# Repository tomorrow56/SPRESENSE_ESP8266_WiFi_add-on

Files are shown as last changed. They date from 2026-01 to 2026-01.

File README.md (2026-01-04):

# SPRESENSE Wi-Fi Add-on

 [English](README_EN.md)

## 概要
Sonyの省電力で高性能なIoT開発ボードSPRESENSEにWi-FI機能を追加するためのアドオンボードです。
ESP8266(ESP-WROOM-02, 技適取得済)を搭載、SPRESENSEとEP8266の間の通信は [Espressif標準のATコマンド](ESP8266_AT_command/) を使用します。

## 主な仕様
- ESP8266(ESP-WROOM-02)を搭載
- SPRESENSEメインボード上面の拡張コネクタに直接装着可能（レベルシフタ搭載）
- ハーフサイズ設計で他のハーフサイズモジュールと同時に使用可能
- I2C・SPI接続のモジュールとの同時使用が可能（一部制限あり）
- 技適取得済み

### v2.2について(2026年1月リリース)
従来のバージョン(v1.1)と比較して、以下の変更があります：
- ESP8266 Deep sleep機能への対応

この対応のため、リセット回路の設計を変更しました。そのため、従来のv1.1のソフトウエアを使用する場合は、以下のリセットピン(D21)の制御の追加が必要となります。

```cpp
#define rst_pin PIN_D21   // ESP8266のリセットピン, Hでリセット

void setup() {
  // ESP8266のリセットピンの設定
  pinMode(rst_pin, OUTPUT);
  // ESP8266のリセットを解除する(リセットピンをLにする)
  digitalWrite(rst_pin, LOW);

```

## 製品画像 (基板の色は予告なく変更になる場合があります)

### v1.1

#### 基板表面

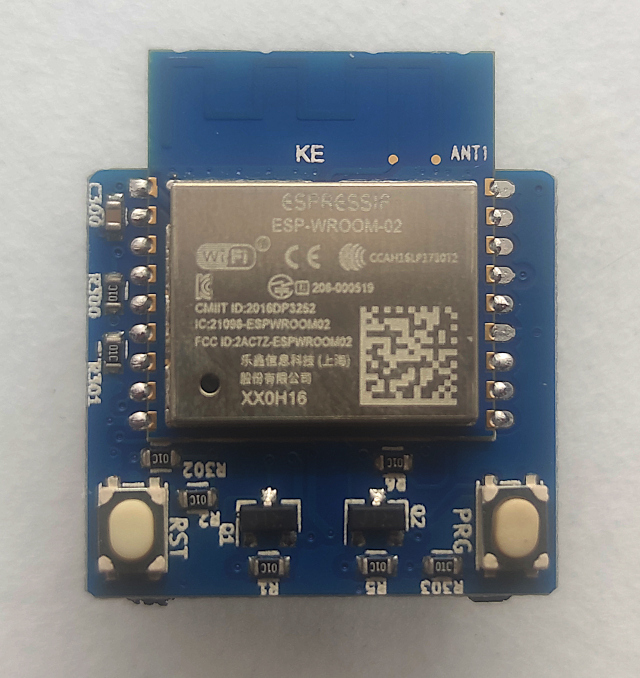
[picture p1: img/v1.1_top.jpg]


#### 基板裏面

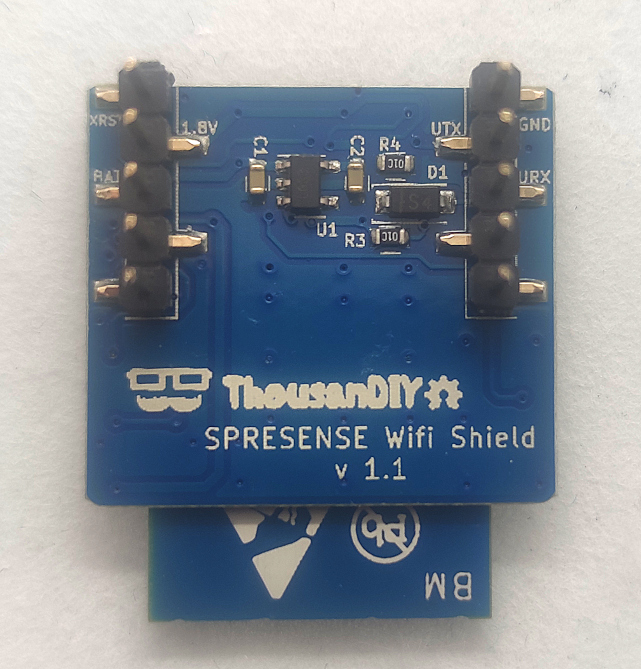
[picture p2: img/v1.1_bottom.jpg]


#### SPRESENSEへ取り付けた状態 (SPRESENSEは付属しません)

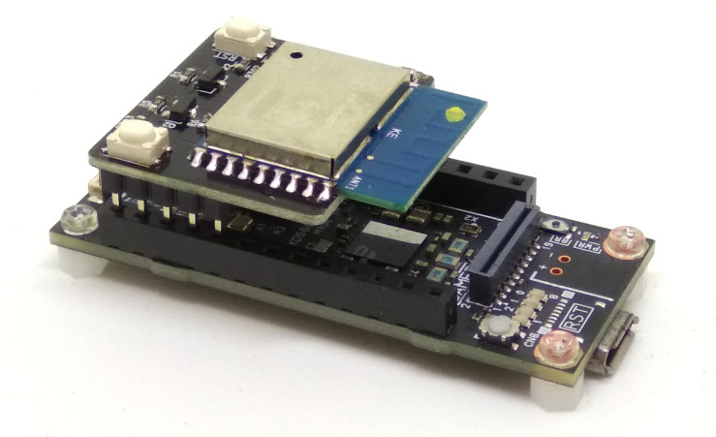
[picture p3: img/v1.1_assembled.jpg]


### v2.2

#### 基板表面

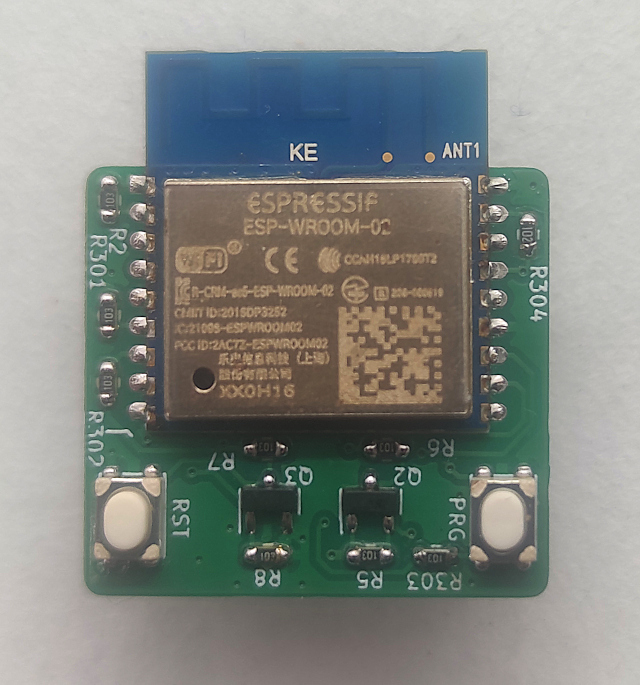
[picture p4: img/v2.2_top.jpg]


#### 基板裏面

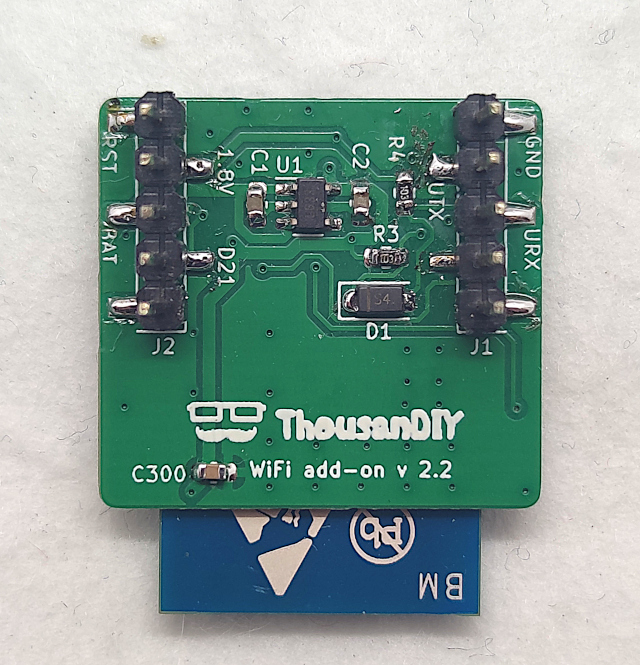
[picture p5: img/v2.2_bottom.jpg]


#### SPRESENSEへ取り付けた状態 (SPRESENSEは付属しません)

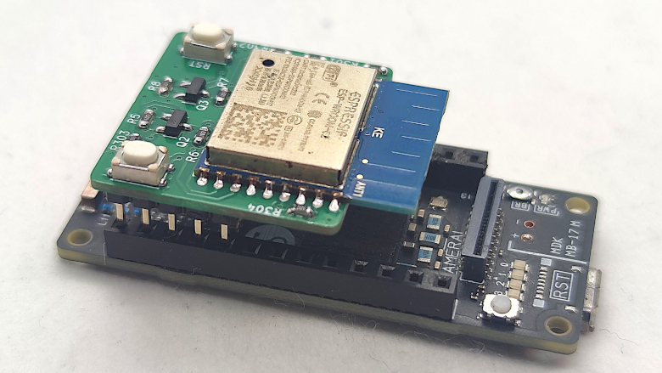
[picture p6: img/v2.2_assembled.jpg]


## 回路図

### v1.1回路図

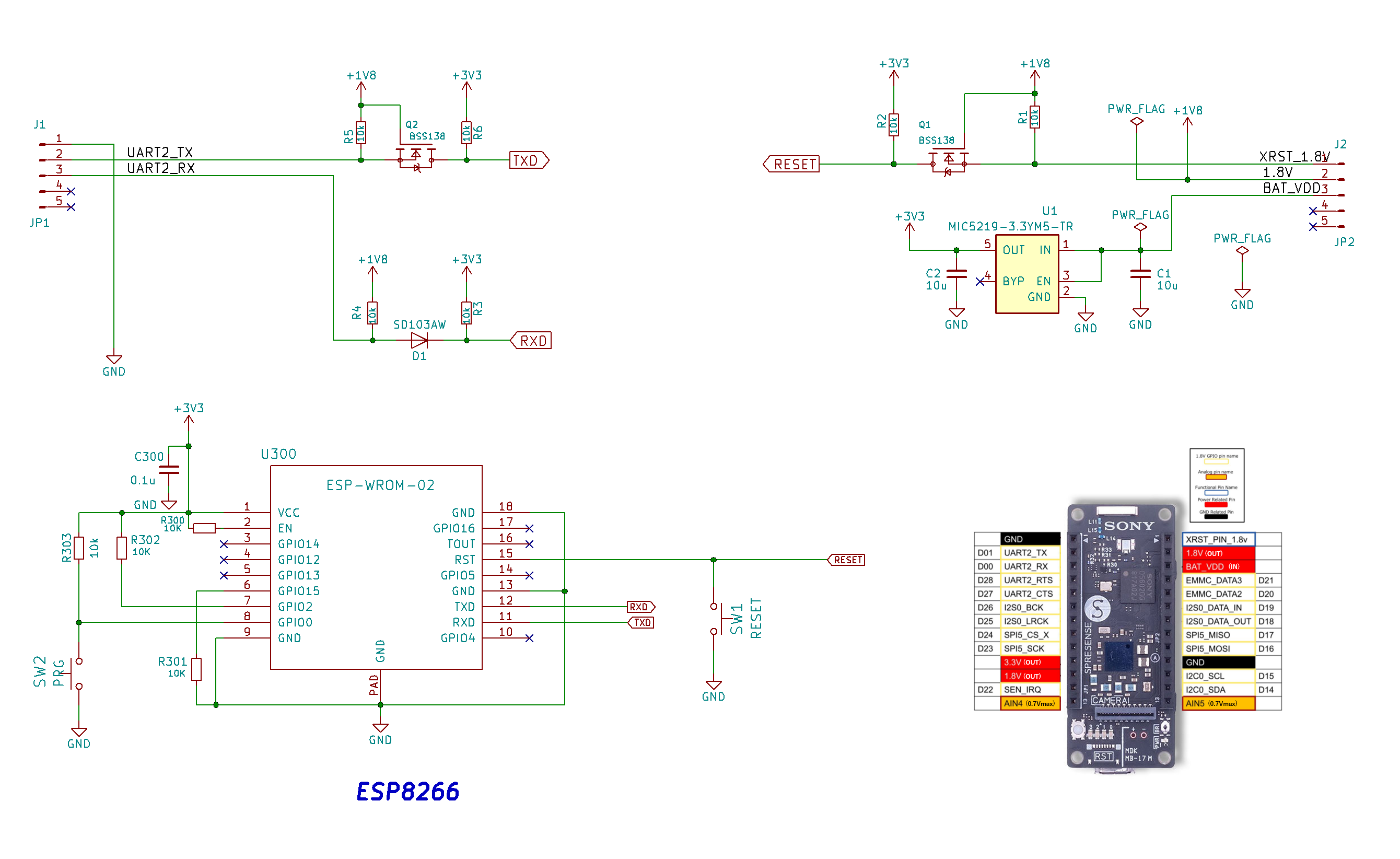
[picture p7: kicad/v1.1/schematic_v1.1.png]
v1.1回路図


### v2.2回路図

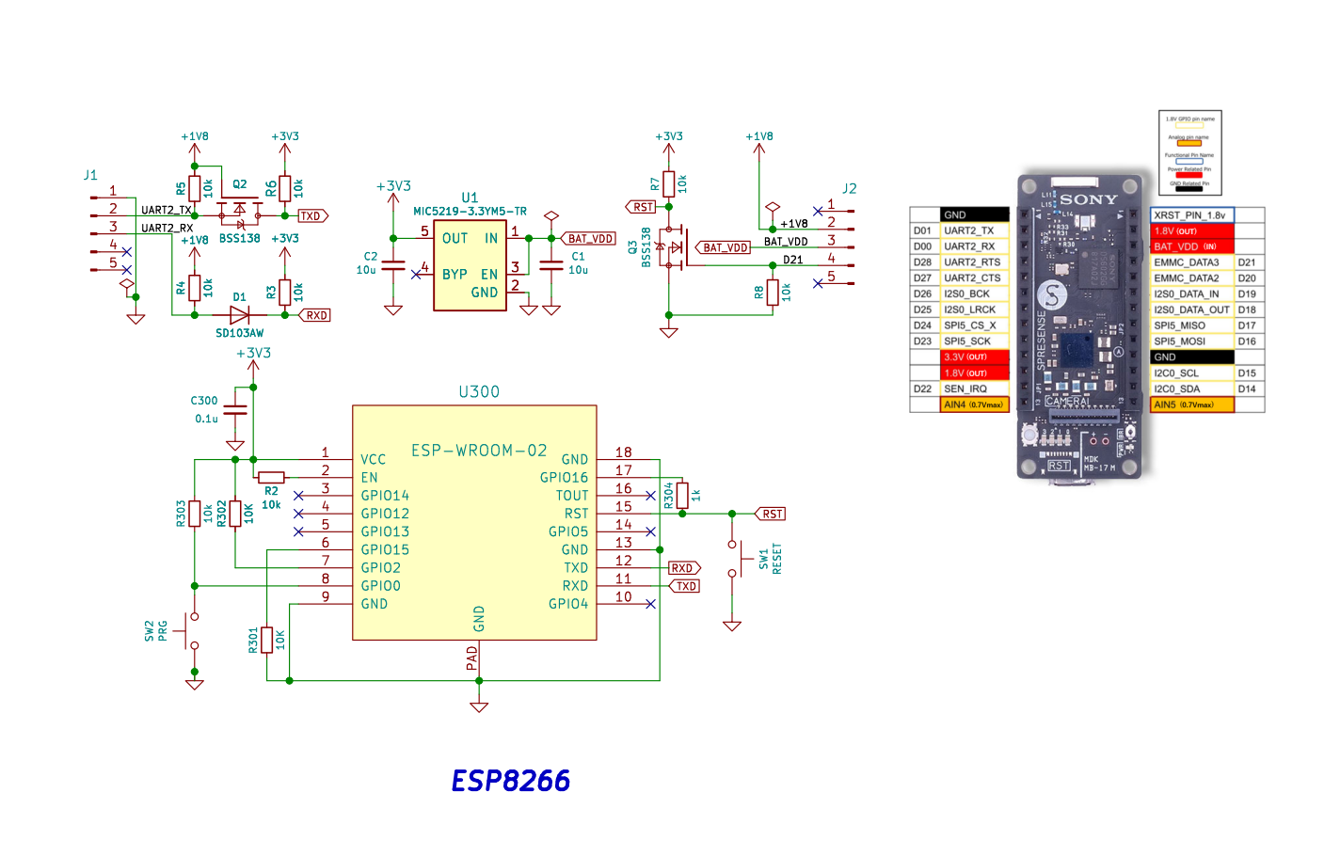
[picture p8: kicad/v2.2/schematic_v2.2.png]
v2.2回路図


## 基板設計データ

基板設計データはKiCadプロジェクト形式で提供されています。
- v1.1: `kicad/v1.1/`
- v2.2: `kicad/v2.2/`

各バージョンの基板設計データには、回路図、PCBレイアウト、部品リストなどが含まれています。

## サンプルコード

各バージョンのサンプルコードは、`example/`ディレクトリ以下に格納されています。
- v1.1: `example/v1.1/`
- v2.2: `example/v2.2/`

各サンプルコードは、SPRESENSEのArduino IDE環境で動作するように設計されています。
詳細な使用方法は各サンプルコードのコメントを参照してください。

## ライセンス

このプロジェクトはGNU General Public License v3.0ライセンスの下で提供されます。詳細は[LICENSE](LICENSE)ファイルを参照してください。

## 作者

- [tomorrow56](https://github.com/tomorrow56)

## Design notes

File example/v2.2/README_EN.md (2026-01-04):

# SPRESENSE v2.2 Examples

[日本語](README.md)

## Overview

This directory contains sample programs for the SPRESENSE Wi-Fi add-on v2.2. Version 2.2 supports ESP8266 Deep Sleep functionality, and when combined with SPRESENSE's Cold Sleep feature, it can significantly reduce power consumption during battery operation.

## Sample List

### 1. SPRESENSE_PIR_to_LINE

This is a low-power IoT application that sends messages to the LINE Messaging API via SPRESENSE and ESP8266, triggered by PIR (motion) sensor interrupt detection.

#### Features

- **Ultra-low power design**: Reduces power consumption to several μA by putting ESP8266 in Deep Sleep and SPRESENSE in Cold Sleep during standby
- **Event-driven**: Automatically wakes up when the PIR sensor detects human presence, sends messages, and returns to sleep mode
- **Real-time notifications**: Can send instant notifications to the LINE app

#### Operation Overview

1. **Initialization**: Initialize SPRESENSE and ESP8266, establish Wi-Fi connection
2. **Sleep transition**: Put ESP8266 in Deep Sleep and SPRESENSE in Cold Sleep
3. **Event detection**: PIR sensor detects human presence and wakes up SPRESENSE
4. **Processing**: Wake up ESP8266 and send messages via LINE Messaging API
5. **Return to sleep**: Return both chips to sleep mode after processing completion

#### Required Hardware

- SPRESENSE main board
- SPRESENSE Wi-Fi add-on v2.2
- PIR sensor module (output: HIGH/LOW digital signal)
- Power supply (battery or USB power)

#### Configuration

The following settings are required before use:

- Wi-Fi access point information (SSID, password)
- LINE Messaging API channel access token
- Destination LINE group or user ID

For detailed configuration methods, please refer to the comments in each sketch.

### 2. Library/ESP8266_LINE_Messaging_API

An Arduino library for easily using the LINE Messaging API with SPRESENSE + ESP8266.

#### Features

- LINE Messaging API v3.0 compatible
- Text message sending functionality
- Simple initialization and authentication process
- Error handling functionality

#### Usage

After installing the library in Arduino IDE, follow these steps with reference to the sample sketch:

1. Include the library
2. Set the access token
3. Establish Wi-Fi connection
4. Call the message sending function

For detailed API reference, please refer to the comments in the library.

## Power Saving Features

### Deep Sleep (ESP8266)

- Power consumption: Approx. 10μA
- Wake-up time: Approx. 200ms
- Wakes up via reset pin (D21) control

### Cold Sleep (SPRESENSE)

- Power consumption: Approx. 1μA (excluding RTC)
- Wake-up time: Approx. 1ms
- Wakes up via GPIO interrupt

### Combined Effect

By combining both sleep functions, the operating life during battery operation can be significantly extended. For example, for applications that detect events several times per day, operation for several months to years with coin batteries is possible.

## Important Notes

- This sample is exclusive to SPRESENSE Wi-Fi add-on v2.2. It does not work with v1.1.
- Deep Sleep functionality requires connection of the reset pin (D21).
- Sleep power consumption varies depending on supply voltage and ambient temperature.
- Internet connection is required for using LINE Messaging API.

## License

Each sample code and library is provided under the GNU General Public License v3.0, same as the entire project.

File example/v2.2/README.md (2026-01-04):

# SPRESENSE v2.2 Examples

[English](README_EN.md)

## 概要

このディレクトリには、SPRESENSE Wi-Fi add-on v2.2 を使用したサンプルプログラムが含まれています。v2.2 では ESP8266 の Deep Sleep 機能に対応し、SPRESENSE の Cold Sleep 機能と組み合わせることで、バッテリー駆動時の消費電力を大幅に削減できます。

## サンプル一覧

### 1. SPRESENSE_PIR_to_LINE

PIR（人感）センサーの割込み検出をトリガーとして、SPRESENSEとESP8266経由でLINE Messaging APIにメッセージを送信する省電力IoTアプリケーションです。

#### 特徴

- **超低消費電力設計**: 待機時は ESP8266 を Deep Sleep、SPRESENSE を Cold Sleep にすることで、消費電力を数μAレベルに抑制
- **イベント駆動**: PIRセンサーによる人体検出で自動的に起動し、メッセージ送信後に再びスリープ状態へ移行
- **リアルタイム通知**: LINEアプリに即時通知を送信可能

#### 動作概要

1. **初期化**: SPRESENSEとESP8266を初期化し、Wi-Fi接続を確立
2. **スリープ移行**: ESP8266をDeep Sleep、SPRESENSEをCold Sleepに移行
3. **イベント検出**: PIRセンサーが人体を検出し、SPRESENSEを起動
4. **処理実行**: ESP8266を起動し、LINE Messaging API経由でメッセージを送信
5. **再スリープ**: 処理完了後、再び両チップをスリープ状態へ

#### 必要なハードウェア

- SPRESENSEメインボード
- SPRESENSE Wi-Fi add-on v2.2
- PIRセンサーモジュール（出力：HIGH/LOWデジタル信号）
- 電源（バッテリーまたはUSB電源）

#### 設定

使用前に以下の設定が必要です：

- Wi-Fiアクセスポイント情報（SSID、パスワード）
- LINE Messaging APIのチャネルアクセストークン
- 通知先のLINEグループまたはユーザーID

詳しい設定方法は、各スケッチのコメントを参照してください。

### 2. Library/ESP8266_LINE_Messaging_API

LINE Messaging APIをSPRESENSE + ESP8266で簡単に利用するためのArduinoライブラリです。

#### 機能

- LINE Messaging API v3.0対応
- テキストメッセージ送信機能
- 簡単な初期化と認証処理
- エラーハンドリング機能

#### 使用方法

ライブラリをArduino IDEにインストール後、サンプルスケッチを参考に以下の手順で使用します：

1. ライブラリをインクルード
2. アクセストークンを設定
3. Wi-Fi接続を確立
4. メッセージ送信関数を呼び出し

詳細なAPIリファレンスはライブラリ内のコメントを参照してください。

## 省電力機能について

### Deep Sleep (ESP8266)

- 消費電力: 約10μA
- 起動時間: 約200ms
- リセットピン（D21）制御で起動

### Cold Sleep (SPRENSE)

- 消費電力: 約1μA（RTC除く）
- 起動時間: 約1ms
- GPIO割込みで起動

### 組合せ効果

両スリープ機能を組み合わせることで、バッテリー駆動時の動作寿命を大幅に延長できます。例えば、1日数回のイベント検知用途であれば、コイン電池での数ヶ月〜数年の駆動も可能です。

## 注意事項

- 本サンプルはSPRESENSE Wi-Fi add-on v2.2専用です。v1.1では動作しません。
- Deep Sleep機能を使用するため、リセットピン（D21）の接続が必要です。
- 電源電圧や周囲温度によってスリープ時の消費電力は変動します。
- LINE Messaging APIの利用にはインターネット接続が必要です。

## ライセンス

各サンプルコードおよびライブラリは、プロジェクト全体と同じくGNU General Public License v3.0の下で提供されます。

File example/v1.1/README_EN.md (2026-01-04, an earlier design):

# SPRESENSE v1.1 Examples

[日本語](README.md)

## Overview

This directory contains sample programs for the SPRESENSE Wi-Fi add-on v1.1. Version 1.1 provides basic Wi-Fi communication functionality and can serve as a foundation for various IoT applications.

## Sample List

### 1. SPRESENSE_ESP8266

A simple sample for verifying the basic operation of the Wi-Fi add-on.

#### Features

- Connection to Wi-Fi access points
- HTTP client communication with web servers
- Display of communication status via serial monitor

#### Characteristics

- Basic sample for first-time users of SPRESENSE Wi-Fi add-on
- Learn basic AT command usage
- Ideal for testing ESP8266 communication

### 2. SPRESENSE_ESP8266_ambient

A sample for sending sensor data to Ambient (IoT data visualization service).

#### Features

- Periodic sensor data acquisition
- Data transmission to Ambient server
- Data visualization through graphs

#### Requirements

- Ambient account and channel ID
- Sensors (temperature, humidity, etc.)

### 3. SPRESENSE_SERIAL_TEST

A sample for testing serial communication between SPRESENSE and ESP8266.

#### Features

- Bidirectional serial communication testing
- AT command send/receive verification
- Communication speed and stability verification

### 4. SPRESENSE_Sparkfun_ESP8266_Phant

A sample for sending data to SparkFun Phant service.

#### Features

- Data posting to Phant server
- IoT data logging
- Cloud data store integration

### 5. SPRESENSE_Sparkfun_ESP8266_Ping

A Ping test sample for verifying network connectivity.

#### Features

- Ping transmission to specified hosts
- Network latency measurement
- Connection status monitoring

### 6. SPRESENSE_Sparkfun_ESP8266_Shield_Demo

A demonstration showing basic usage of the SparkFun ESP8266 Shield.

#### Features

- Wi-Fi shield initialization
- Various network service usage examples
- Practical application templates

## Library

### SparkFun ESP8266 AT Arduino Library

Arduino library used in v1.1 samples.

#### Features

- Simple interface for ESP8266 AT commands
- Wi-Fi connection management
- HTTP/TCP/UDP communication
- DNS resolution

#### Usage

1. Install the library in Arduino IDE
2. Open the sample sketch
3. Modify Wi-Fi settings
4. Upload sketch to SPRESENSE

## Hardware Requirements

- SPRESENSE main board
- SPRESENSE Wi-Fi add-on v1.1
- USB cable (for programming)
- Wi-Fi access point

## Configuration

All samples require the following configuration:

```cpp
// Wi-Fi settings
const char* ssid = "your_wifi_ssid";
const char* password = "your_wifi_password";
```

For sample-specific configurations, please refer to the comments in each sketch.

## Important Notes

- This sample is exclusive to SPRESENSE Wi-Fi add-on v1.1
- Does not support v2.2 Deep Sleep functionality
- Requires 2.4GHz band Wi-Fi access points
- Some samples require external service accounts

## License

Each sample code and library is provided under the GNU General Public License v3.0, same as the entire project.

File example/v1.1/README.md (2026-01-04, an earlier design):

# SPRESENSE v1.1 Examples

[English](README_EN.md)

## 概要

このディレクトリには、SPRESENSE Wi-Fi add-on v1.1 を使用したサンプルプログラムが含まれています。v1.1 は基本的なWi-Fi通信機能を提供し、様々なIoTアプリケーションの基礎として利用できます。

## サンプル一覧

### 1. SPRESENSE_ESP8266

Wi-Fi add-onの基本的な動作を確認するためのシンプルなサンプルです。

#### 機能

- Wi-Fiアクセスポイントへの接続
- HTTPクライアントによるWebサーバーとの通信
- シリアルモニターによる通信状態の表示

#### 特徴

- 初めてSPRESENSE Wi-Fi add-onを使用する方向けの基本サンプル
- ATコマンドの基本的な使用方法を学習できます
- ESP8266との通信テストに最適

### 2. SPRESENSE_ESP8266_ambient

Ambient（IoTデータ可視化サービス）にセンサーデータを送信するサンプルです。

#### 機能

- センサーデータの定期的な取得
- Ambientサーバーへのデータ送信
- グラフによるデータ可視化

#### 必要なもの

- AmbientアカウントとチャネルID
- センサー（温度、湿度など）

### 3. SPRESENSE_SERIAL_TEST

SPRESENSEとESP8266間のシリアル通信をテストするサンプルです。

#### 機能

- シリアル通信の双方向テスト
- ATコマンドの送受信確認
- 通信速度と安定性の検証

### 4. SPRESENSE_Sparkfun_ESP8266_Phant

SparkFun Phantサービスにデータを送信するサンプルです。

#### 機能

- Phantサーバーへのデータ投稿
- IoTデータロギング
- クラウドデータストア連携

### 5. SPRESENSE_Sparkfun_ESP8266_Ping

ネットワーク接続を確認するためのPingテストサンプルです。

#### 機能

- 指定ホストへのPing送信
- ネットワーク遅延測定
- 接続状態の監視

### 6. SPRESENSE_Sparkfun_ESP8266_Shield_Demo

SparkFun ESP8266 Shieldの基本的な使用方法を示すデモンストレーションです。

#### 機能

- Wi-Fiシールドの初期化
- 各種ネットワークサービスの利用例
- 実用的なアプリケーションの雛形

## ライブラリ

### SparkFun ESP8266 AT Arduino Library

v1.1サンプルで使用されているArduinoライブラリです。

#### 機能

- ESP8266 ATコマンドの簡単なインターフェース
- Wi-Fi接続管理
- HTTP/TCP/UDP通信
- DNS解決

#### 使用方法

1. Arduino IDEにライブラリをインストール
2. サンプルスケッチを開く
3. Wi-Fi設定を変更
4. スケッチをSPRESENSEに書き込む

## ハードウェア要件

- SPRESENSEメインボード
- SPRESENSE Wi-Fi add-on v1.1
- USBケーブル（プログラミング用）
- Wi-Fiアクセスポイント

## 設定

すべてのサンプルで、以下の設定が必要です：

```cpp
// Wi-Fi設定
const char* ssid = "your_wifi_ssid";
const char* password = "your_wifi_password";
```

各サンプル固有の設定については、スケッチ内のコメントを参照してください。

## 注意事項

- 本サンプルはSPRESENSE Wi-Fi add-on v1.1専用です
- v2.2のDeep Sleep機能には対応していません
- Wi-Fi接続には2.4GHz帯のアクセスポイントが必要です
- 一部のサンプルでは外部サービスのアカウントが必要です

## ライセンス

各サンプルコードおよびライブラリは、プロジェクト全体と同じくGNU General Public License v3.0の下で提供されます。

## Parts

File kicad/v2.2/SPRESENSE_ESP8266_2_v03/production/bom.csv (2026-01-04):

Designator | Footprint | Quantity | Value | LCSC Part #
C1, C2 | 0603 | 2 | 10u
C300 | 0603 | 1 | 0.1u
D1 | D_SOD-123F | 1 | SD103AW
J1 | PinHeader_1x05_P2.54mm_Vertical_SMD_Pin1Right | 1 | JP1
J2 | PinHeader_1x05_P2.54mm_Vertical_SMD_Pin1Left | 1 | JP2
Q2, Q3 | SOT-23 | 2 | BSS138
R2, R3, R301, R302, R303, R4, R5, R6, R7, R8 | 0603 | 10 | 10k
R304 | 0603 | 1 | 1k
SW1 | SW_SPST_PTS810 | 1 | RESET
SW2 | SW_SPST_PTS810 | 1 | PRG
U1 | SOT-23-5 | 1 | MIC5219-3.3YM5-TR
U300 | ESP-13-WROOM-02_2 | 1 | ESP-WROOM-02

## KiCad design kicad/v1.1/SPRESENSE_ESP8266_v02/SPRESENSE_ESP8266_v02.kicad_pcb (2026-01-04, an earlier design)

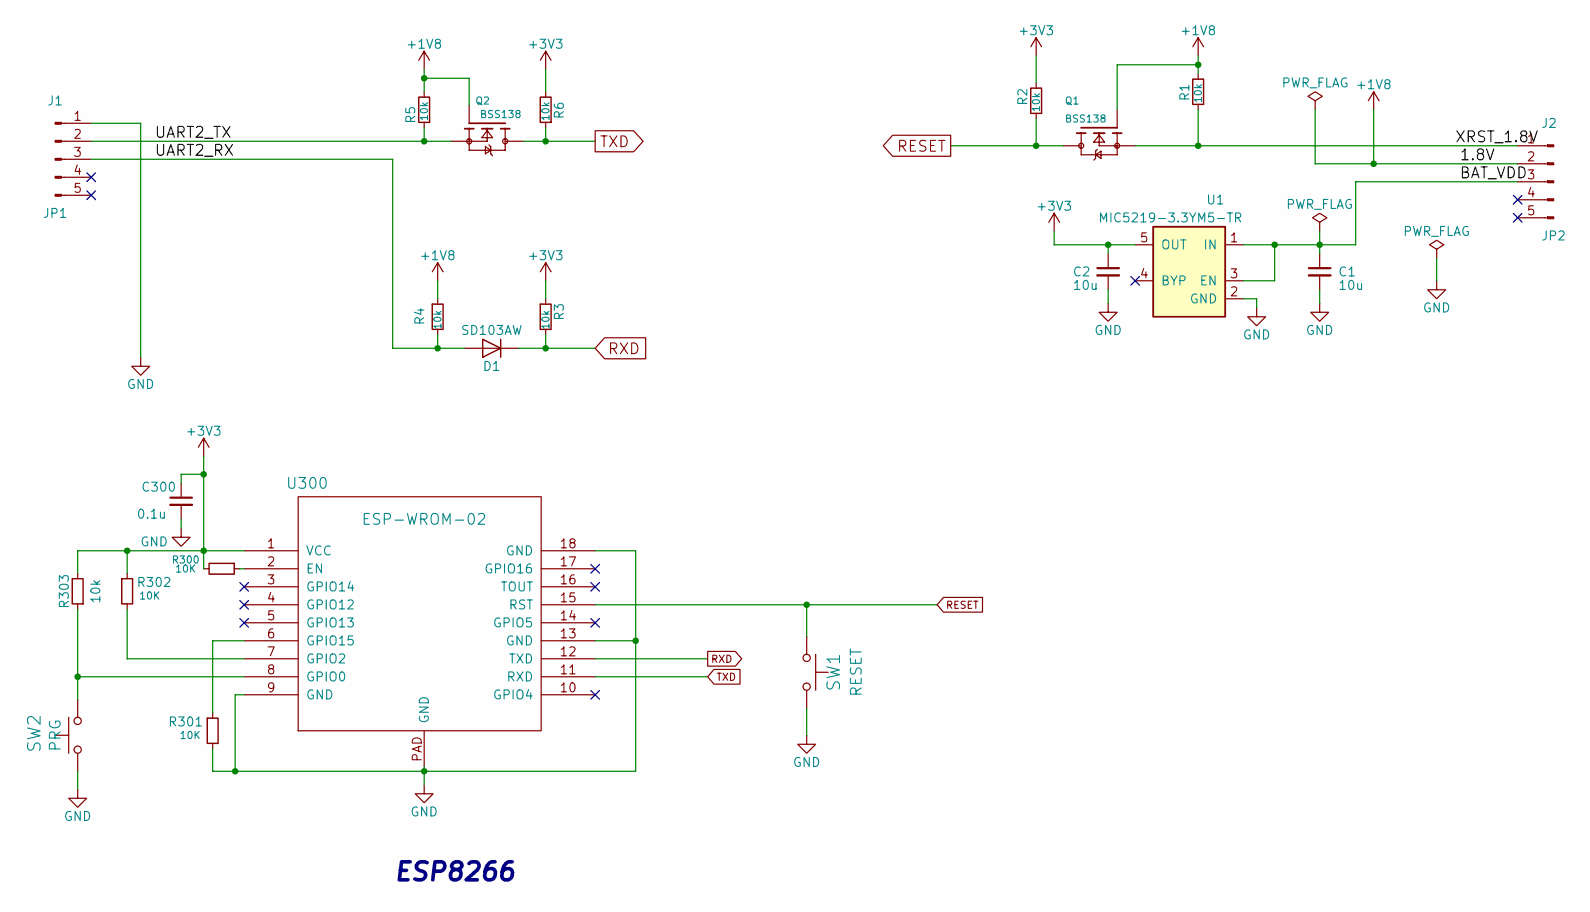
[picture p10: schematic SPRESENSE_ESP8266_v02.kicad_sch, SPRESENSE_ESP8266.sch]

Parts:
C1, C2: 10u; C_0603
C300: 0.1u; C_0603
D1: SD103AW; D_SOD-123F
J1: JP1; Pin_Header_Straight_1x05_Pitch2.54mm_SMD_Pin1Right
J2: JP2; Pin_Header_Straight_1x05_Pitch2.54mm_SMD_Pin1Left
Q1, Q2: BSS138; SOT-23
R1, R2, R3, R4, R5, R6, R303: 10k; R_0603
R300, R301, R302: 10K; R_0603
SW1: RESET; SW_SPST_PTS810
SW2: PRG; SW_SPST_PTS810
U1: MIC5219-3.3YM5-TR; SOT-23-5
U300: ESP-WROM-02; ESP-13-WROOM-02

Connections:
+1V8: J2.2, Q1.1 (G), Q2.1 (G), R1.2, R4.1, R5.2
+3V3: C2.1, C300.1, R2.2, R3.1, R6.2, R300.2, R302.1, R303.2, U1.5 (OUT), U300.1 (VCC)
/BAT_VDD: C1.1, J2.3, U1.1 (IN), U1.3 (EN)
/UART2_RX: D1.2 (A), J1.3, R4.2
/UART2_TX: J1.2, Q2.2 (S), R5.1
/XRST_1.8V: J2.1, Q1.2 (S), R1.1
GND: C1.2, C2.2, C300.2, J1.1, R301.2, SW1.1, SW2.1, U1.2 (GND), U300.9 (GND), U300.13 (GND), U300.18 (GND), U300.PAD (GND)
unnamed: R300.1, U300.2 (EN)
unnamed: R301.1, U300.6 (GPIO15)
unnamed: R302.2, U300.7 (GPIO2)
unnamed: R303.1, SW2.2, U300.8 (GPIO0)
RESET: Q1.3 (D), R2.1, SW1.2, U300.15 (RST)
RXD: D1.1 (K), R3.2, U300.12 (TXD)
TXD: Q2.3 (D), R6.1, U300.11 (RXD)

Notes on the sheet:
ESP8266

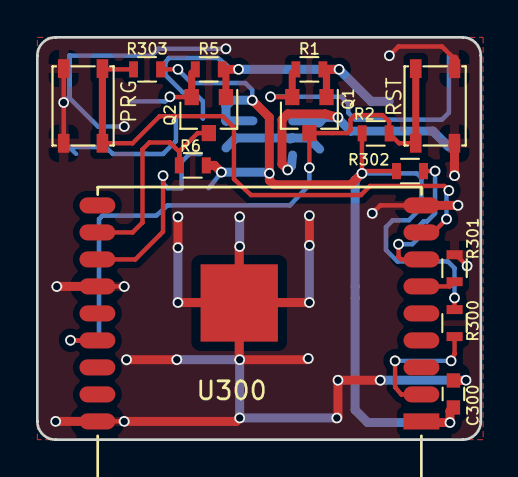
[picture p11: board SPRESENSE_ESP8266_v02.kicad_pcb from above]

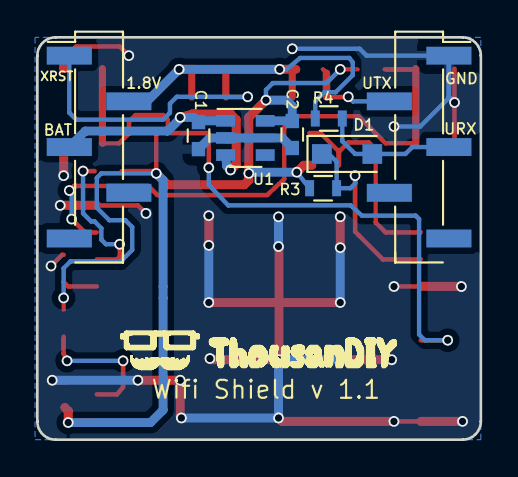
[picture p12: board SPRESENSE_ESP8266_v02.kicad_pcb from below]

Board: 2 copper layers, 24.6 x 22.4 mm, 23 parts (9 on the bottom side), 14 nets.

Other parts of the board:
ref**: val**; TDIY-LOGO-S

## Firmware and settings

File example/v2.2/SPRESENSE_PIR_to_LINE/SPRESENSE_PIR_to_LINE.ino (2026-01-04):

/************************************************************
* ESP8266 WiFi add-on for SPRESENSE
* LINE Messaging API Send Message Library and DeepSleep Example
* Copyright(c) @tomorrow56 All rights reserved.
* ESP8266 baudrate: 115200 baud
************************************************************/

#include "Arduino.h"
#include "LineMessenger.h"
#include <LowPower.h>

#define debug true       // デバッグモード

#define rst_pin PIN_D21   // ESP8266のリセットピン, Hでリセット
#define wake_pin PIN_D14  // SPRESENSEのWakeUpトリガピン, LでWakeUp

// WiFiとLINEの設定
const char* ssid = "<your SSID>";
const char* password = "<your Password>";
// 以下からLINEチャネルアクセストークンを取得する
// https://developers.line.biz/ja/docs/messaging-api/getting-started/
const char* accessToken =  "<your LINE Access Token>";

// Line Messaging API インスタンス作成
LineMessenger line;

bool wakeUpFlag = false;    // WakeUp割り込みフラグ, trueでWakeUp
bool sendCompleteFlag = false;  // LINE Message 送信フラグ, trueで送信完了

bootcause_e bc; // 起動要因を格納する変数

// 起動要因の列挙型
const char* boot_cause_strings[] = {
  "Power On Reset with Power Supplied",
  "System WDT expired or Self Reboot",
  "Chip WDT expired",
  "WKUPL signal detected in deep sleep",
  "WKUPS signal detected in deep sleep",
  "RTC Alarm expired in deep sleep",
  "USB Connected in deep sleep",
  "Others in deep sleep",
  "SCU Interrupt detected in cold sleep",
  "RTC Alarm0 expired in cold sleep",
  "RTC Alarm1 expired in cold sleep",
  "RTC Alarm2 expired in cold sleep",
  "RTC Alarm Error occurred in cold sleep",
  "Unknown(13)",
  "Unknown(14)",
  "Unknown(15)",
  "GPIO detected in cold sleep",
  "GPIO detected in cold sleep",
  "GPIO detected in cold sleep",
  "GPIO detected in cold sleep",
  "GPIO detected in cold sleep",
  "GPIO detected in cold sleep",
  "GPIO detected in cold sleep",
  "GPIO detected in cold sleep",
  "GPIO detected in cold sleep",
  "GPIO detected in cold sleep",
  "GPIO detected in cold sleep",
  "GPIO detected in cold sleep",
  "SEN_INT signal detected in cold sleep",
  "PMIC signal detected in cold sleep",
  "USB Disconnected in cold sleep",
  "USB Connected in cold sleep",
  "Power On Reset",
};

// ESP8266からの受信バッファをクリアする関数
void clearSerial2Buffer() {
  while (Serial2.available() > 0) {
    Serial2.read(); // バッファから1バイトずつ読み出して捨てる
  }
}

// ESP8266をリセットする関数
void resetESP8266() {
  Serial.println("ESP8266 has been reset...");
  digitalWrite(rst_pin, HIGH);  // リセットピンをHにする
  delay(200);
  digitalWrite(rst_pin, LOW);  // リセットピンをLにする

  //ESP8266起動時のゴミデータを捨てる
  delay(250);
  clearSerial2Buffer();

  digitalWrite(LED1, HIGH);  // LED1を点灯
}

// ESP8266をDeep Sleepに移行する関数
void gotoSleepESP8266() {
  // ESP8266をDeep Sleepに移行（最大時間: 約71分、単位はマイクロ秒）
  // AT+GSLP=0は無限スリープ（外部リセットが必要）

  line.sendCommand("AT+GSLP=0", 1000);
  Serial.println("ESP8266 goes to deep sleep mode...");
  
  digitalWrite(LED3, HIGH);  // LED3を点灯

  delay(1000); // Deep Sleepに完全に入るまでの待ち時間
}

// SPRESENSEの起動要因を表示する関数 
void printBootCause(bootcause_e bc) {
  Serial.println("--------------------------------------------------");
  Serial.print("Boot Cause: ");
  Serial.print(boot_cause_strings[bc]);
  if ((COLD_GPIO_IRQ36 <= bc) && (bc <= COLD_GPIO_IRQ47)) {
    // Wakeup by GPIO
    int pin = LowPower.getWakeupPin(bc);
    Serial.print(" <- pin ");
    Serial.print(pin);
  }
  Serial.println();
  Serial.println("--------------------------------------------------");
}

// SPRESENSEのWakeUp割り込み関数
void wakeUpISR() {
 // Print the boot cause
 printBootCause(bc);
 Serial.println("wakeup from cold sleep");
 wakeUpFlag = true;  // set flag
}

// SPRESENSEをCold Sleepに移行する関数
void gotoSleep() {
 Serial.println("SPRESENSE goes to cold sleep...");
 Serial.println("Wait until wake_pin is low.");

 digitalWrite(LED0, LOW);  // LED0を消灯
 digitalWrite(LED1, LOW);  // LED1を消灯
 digitalWrite(LED2, LOW);  // LED2を消灯
 digitalWrite(LED3, LOW);  // LED3を消灯

 delay(100);
 LowPower.coldSleep();
}

void setup() {

  // シリアル通信の初期化
  Serial.begin(115200);    // SPRESENSEデバッグ用シリアル
  Serial2.begin(115200);   // ESP8266用シリアル
  // シリアル通信が確立するまで待機
  while (!Serial);
  while (!Serial2);

  // LEDの設定
  pinMode(LED0, OUTPUT);
  pinMode(LED1, OUTPUT);
  pinMode(LED2, OUTPUT);
  pinMode(LED3, OUTPUT);

  // ESP8266のリセットピンの設定
  pinMode(rst_pin, OUTPUT);
  // ESP8266のリセットを解除する(リセットピンをLにする)
  digitalWrite(rst_pin, LOW);

  //ESP8266起動時のゴミデータを捨てる
  delay(250);
  clearSerial2Buffer();

  // SPRESENSE LowPowerライブラリの初期化
  LowPower.begin();
  // 起動要因を取得
  bc = LowPower.bootCause();
      
  //  WakeUp割り込みではない場合は開始メッセージを表示
  if ((bc == POR_SUPPLY) || (bc == POR_NORMAL)) {
    Serial.println("--------------------------------------------------");
    Serial.println("DeepSleep->Line Send Message Example");
    Serial.println("--------------------------------------------------");
  }

  digitalWrite(LED0, HIGH);  // LED0を点灯

  // WakeUpピンの設定
  pinMode(wake_pin, INPUT_PULLUP);
  // WakeUp割り込みの設定
  //attachInterrupt(pin, void (*isr)(void), mode, filter);
  attachInterrupt(wake_pin, wakeUpISR, FALLING, true);
  // WakeUpピンによる起動を有効にする
  LowPower.enableBootCause(wake_pin);

  gotoSleepESP8266();  // ESP8266をDeep Sleepに移行

  // WakeUp割り込み以外で起動した場合はSPRESENSEをCold Sleepに移行
  if (wakeUpFlag == false) {
    gotoSleep();  // Cold sleep
    }
}

void loop() {
  if (wakeUpFlag) {
    if(sendCompleteFlag == false) {   // LINE Messageを送信完了していない場合
      // ESP8266をリセットしてDeep Sleepから起動
       resetESP8266();

      Serial.println("ESP8266 was woken up from deep sleep by the RST pin.");
      // アクセストークン設定
      line.setAccessToken(accessToken);
      // WiFi接続
      if (line.connectWiFi(ssid, password, debug)) {
        Serial.println("WiFi connected");

        digitalWrite(LED2, HIGH);  // LED2を点灯

        // LINEメッセージ送信
        line.sendMessage("人感センサーが反応しました。部屋に誰かがいる可能性があります。", debug);
      } else {
        Serial.println("WiFi connection failed");
      }
      sendCompleteFlag = true;  // LINE Message 送信完了
      gotoSleepESP8266();  // ESP8266をDeep Sleepに移行
    }
    // WakeUpピンが開放された場合(HIGH)はCold Sleepに移行
    if(digitalRead(wake_pin)) {
      wakeUpFlag = false;
      gotoSleep();  // Cold sleep
    }
  }
  delay(100);
}

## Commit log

2026-01-04 Refactor: Reorganize repository structure and add English README
    - Add .gitignore to exclude macOS metadata and backup files
    - Add README_EN.md with English translation and cross-link
    - Move AT command PDFs to ESP8266_AT_command/ directory
    - Reorganize examples under versioned directories (v1.1/, v2.2/)
    - Add v2.2 examples with LINE messaging API and PIR sensor demo
    - Move KiCad files to versioned directories and add v2.2 schematics
    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
    [SPRESENSE_ESP8266_2_v03.kicad_pcb, SPRESENSE_ESP8266_2_v03.kicad_sch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]
2026-01-04 Add Board Design Data section to README_EN.md
    - Mirror the Japanese README.md addition
    - Include section explaining KiCad project locations and contents
2026-01-04 Add README files for example/v1.1/
    - Create comprehensive Japanese README.md with v1.1 sample descriptions
    - Create English README_EN.md with complete translation
    - Add cross-language links between both versions
    - Document all 6 sample programs and library usage
    - Include hardware requirements and configuration instructions
